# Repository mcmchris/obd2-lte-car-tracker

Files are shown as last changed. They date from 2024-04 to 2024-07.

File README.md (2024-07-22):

# OBD-II LTE Car Tracker
LTE Car Tracker and engine status monitoring connected to the Cloud.

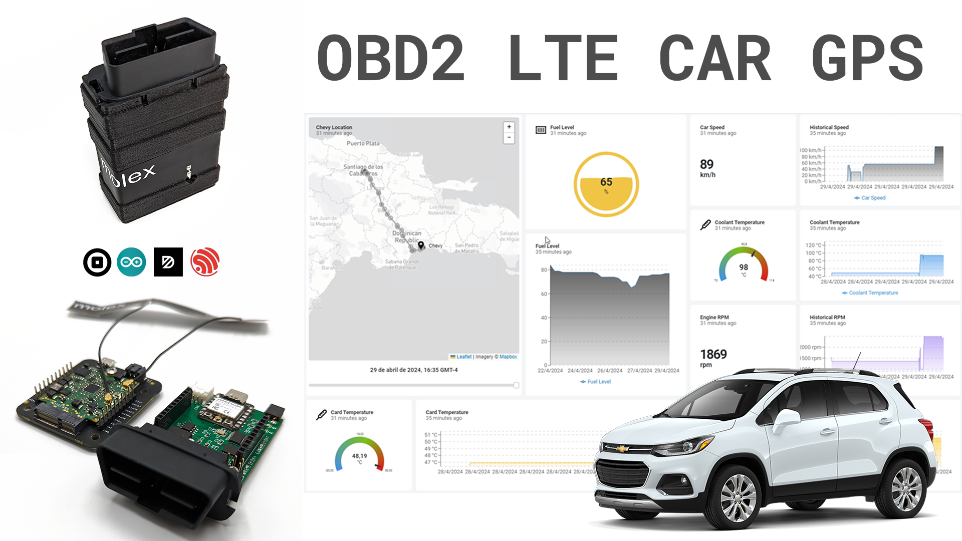
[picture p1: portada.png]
Thumbnail


## Materials

- [XIAO ESP32C3](https://www.seeedstudio.com/Seeed-XIAO-ESP32C3-p-5431.html)
- [Cellular Notecard EMEA](https://shop.blues.com/products/notecard?variant=43940458856689)
- [Notecarrier B](https://shop.blues.com/collections/notecarrier/products/carr-b)
- Custom PCB

## External reference:

- [Serial CAN Module Firmware](https://github.com/Longan-Labs/Serial_CAN_Bus)
- [Longan CAN Module Documentation](https://docs.longan-labs.cc/1030001/)
- [XIAO ESP32C3 Documentation](https://wiki.seeedstudio.com/XIAO_ESP32C3_Getting_Started/)

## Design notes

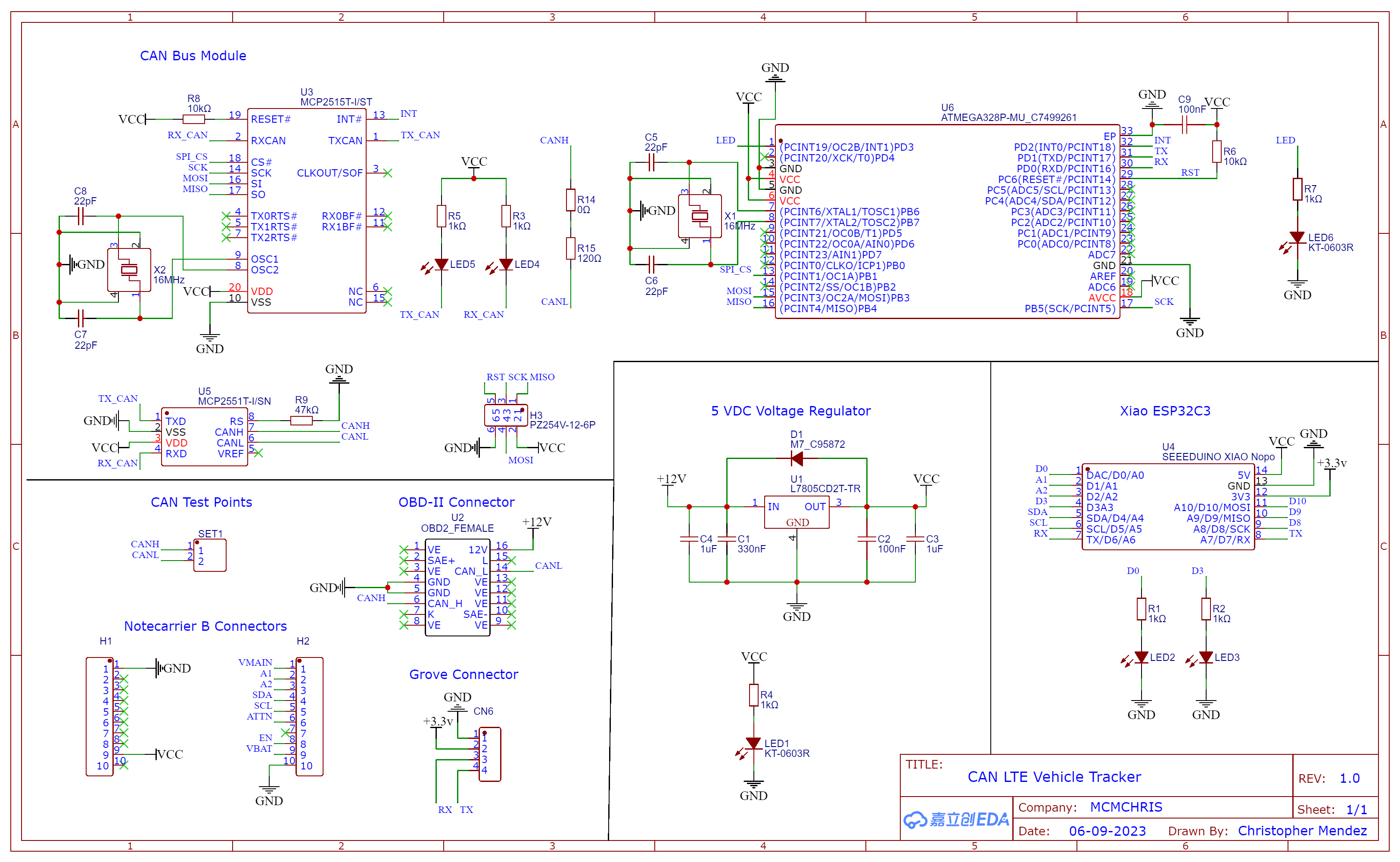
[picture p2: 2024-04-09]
Schematics and PCB files/Schematic_ODB2_car_2024-04-09.png

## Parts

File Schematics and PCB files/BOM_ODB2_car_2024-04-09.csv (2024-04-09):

ID | Name | Designator | Footprint | Quantity | Manufacturer Part | Manufacturer | Supplier | Supplier Part | Price
1 | L7805CD2T-TR | U1 | TO-263-2_L10.0-W9.1-P5.08-LS15.2-TL | 1 |  | ST(意法半导体) | LCSC | C15077 | 0.336
2 | SEEEDUINO XIAO Nopo | U4 | SEEEDUINOXIAO | 1
3 | 330nF | C1 | C0603 | 1 |  | FH(风华) | LCSC | C1615 | 0.01
4 | 100nF | C2,C9 | C0603 | 2 |  | YAGEO(国巨) | LCSC | C14663 | 0.002
5 | 1uF | C3,C4 | C0603 | 2 |  | SAMSUNG(三星) | LCSC | C15849 | 0.005
6 | M7_C95872 | D1 | SMA_L4.3-W2.6-LS5.2-RD | 1 |  | MDD | LCSC | C95872 | 0.007
7 | KT-0603R | LED1,LED6 | LED0603-RD | 2 |  | KENTO | LCSC | C2286 | 0.005
8 | 19-213/Y2C-CQ2R2L/3T(CY) | LED2,LED3,LED4,LED5 | LED0603-RD-YELLOW | 4 |  | EVERLIGHT(亿光) | LCSC | C72038 | 0.019
9 | 1kΩ | R1,R2,R4,R3,R5,R7 | R0603 | 6 | 0603WAF1001T5E | UNI-ROYAL(厚声) | LCSC | C21190 | 0.001
10 | A2008WR-4P | CN6 | CONN-TH_A2008WR-4P | 1 | A2008WR-4P | Changjiang Connectors | LCSC | C273102
11 | 22pF | C5,C6,C7,C8 | C0402 | 4 | 0402CG220J500NT | FH | LCSC | C1555 | 0.001
12 | 10kΩ | R6,R8 | R0402 | 2 | 0402WGF1002TCE | UNI-ROYAL(厚声) | LCSC | C25744 | 0.001
13 | 47kΩ | R9 | R0603 | 1 | 0603WAF4702T5E | UNI-ROYAL(厚声) | LCSC | C25819 | 0.001
14 | 120Ω | R15 | R0603 | 1 | 0603WAF1200T5E | UNI-ROYAL(厚声) | LCSC | C22787 | 0.001
15 | MCP2515T-I/ST | U3 | TSSOP-20_L6.5-W4.4-P0.65-LS6.4-BL | 1 | MCP2515T-I/ST | MICROCHIP(美国微芯) | LCSC | C185941 | 1.252
16 | MCP2551T-I/SN | U5 | SOIC-8_L5.0-W4.0-P1.27-LS6.0-BL | 1 | MCP2551T-I/SN | MICROCHIP(美国微芯) | LCSC | C49558 | 1.009
17 | ATMEGA328P-MU_C7499261 | U6 | HVQFN-32_L5.0-W5.0-P0.50-TL-EP3.1 | 1 | ATMEGA328P-MU | MICROCHIP(美国微芯) | LCSC | C7499261 | 2.526
18 | 16MHz | X1,X2 | OSC-SMD_4P-L3.2-W2.5-BL | 2 | X322516MLB4SI | YXC(扬兴晶振) | LCSC | C13738 | 0.068
19 | PZ254V-12-6P | H3 | HDR-TH_6P-P2.54-V-M-R2-C3-S2.54 | 1 | PZ254V-12-6P | XFCN(兴飞) | LCSC | C492420 | 0.033
20 | OBD2_FEMALE | U2 | OBD2_FEMALE | 1

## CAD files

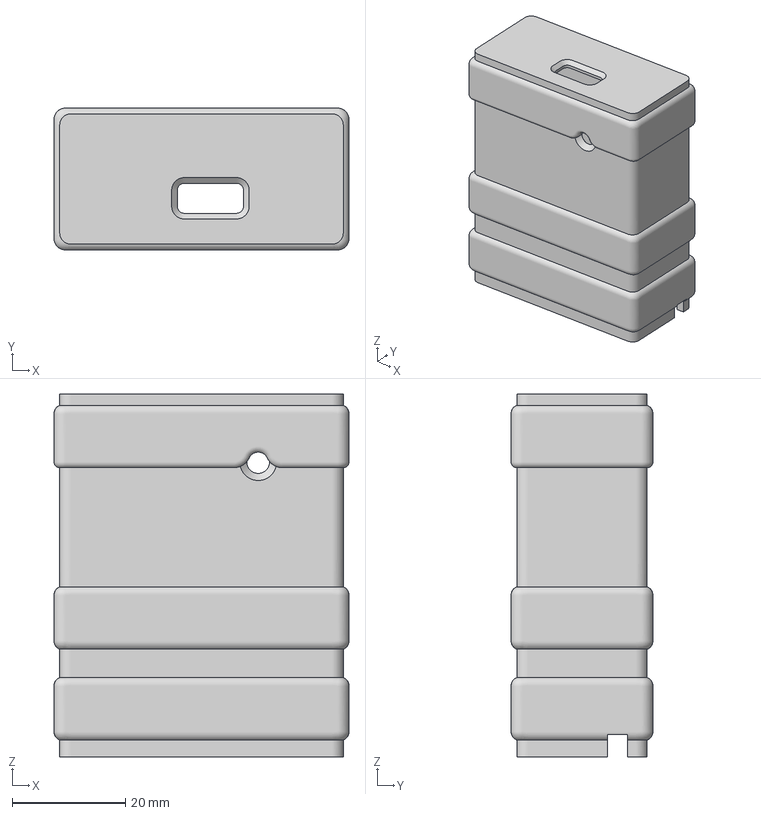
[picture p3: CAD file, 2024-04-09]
3D Files/Case.3mf
52.0 x 25.0 x 64.0 mm

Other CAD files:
3D Files/Case.stl

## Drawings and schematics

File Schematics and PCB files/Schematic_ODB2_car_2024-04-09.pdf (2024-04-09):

## CAN Bus Module

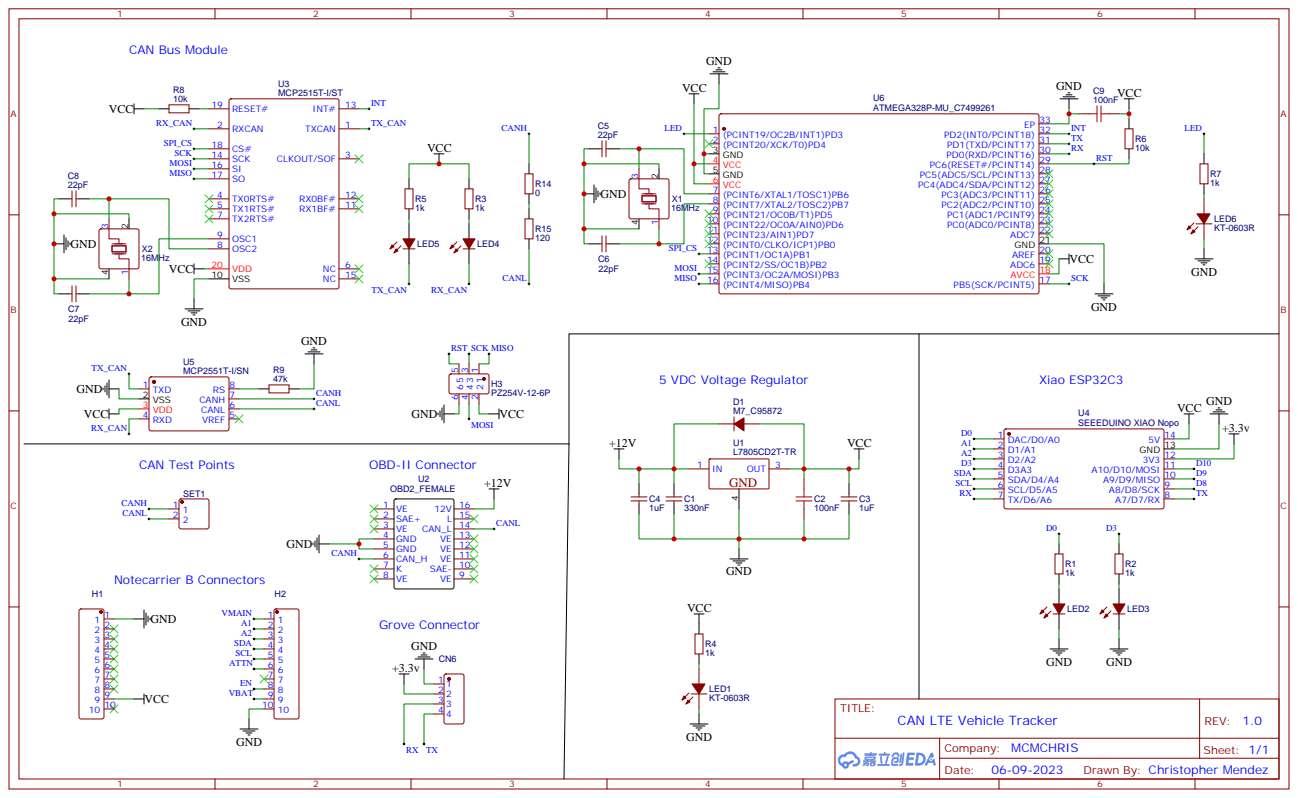
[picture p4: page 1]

SAE- 10 VE 11 VE 12 VE 13 CAN_L 14 L

Drawn By: Christopher Mendez

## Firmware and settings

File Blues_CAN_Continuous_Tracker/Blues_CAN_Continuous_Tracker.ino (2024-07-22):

/*
   MCM - OBD2 Car Tracker

   @Author: Christopher Mendez | MCMCHRIS
   @Date: 04/09/2024 (mm/dd/yy)
   @Brief:
   This firmware runs on a XIAO ESP32C3 microcontroller, it communicates with the vehicle using a CAN-bus transceiver 
   and sends the read data to the Cloud using a Notecard LTE. 

*/

#include <Notecard.h>
#include <Wire.h>
#include <Serial_CAN_Module_ESP.h>

#define serialDebug Serial

#define PRODUCT_UID "***************************"

#define productUID PRODUCT_UID

Notecard notecard;

long previousMillis = 0;
long interval = 60000 * 1;  // 1 minute

Serial_CAN can;

#define STANDARD_CAN_11BIT 1  // That depends on your car. some 1 some 0.

#define PID_ENGIN_PRM 0x0C
#define PID_VEHICLE_SPEED 0x0D
#define PID_COOLANT_TEMP 0x05
#define PID_INTAKE_TEMP 0x0f
#define PID_FUEL_TANK 0x2F  // (100/255)*A
//#define PID_ODOMETER 0xA6

#define LED_A D3
#define LED_B D0


#if STANDARD_CAN_11BIT
#define CAN_ID_PID 0x7DF
#else
#define CAN_ID_PID 0x18db33f1
#endif

int nSpeed = 0;  // speed, 0-200
int nRpm = 0;    // engin speed, 0-999
int nCTemp = 0;  // cooltant temp: 0-999
int nITemp = 0;  //intake temp: 0-999
int nFTank = 0;  // fuel tank level 0-100
float nOdo = 0;

double timeEpoch = 0;
double where_lat = 0;
double where_lon = 0;
double where_when = 0;
double temperature = 0;

bool latch = 0;

/**
 * @brief This function handles the car data send
 */
void sendPid(unsigned char __pid) {
  unsigned char tmp[8] = { 0x02, 0x01, __pid, 0, 0, 0, 0, 0 };
  //Serial.print("SEND PID: 0x");
  //Serial.println(__pid, HEX);

#if STANDARD_CAN_11BIT
  can.send(CAN_ID_PID, 0, 0, 8, tmp);  // SEND TO ID:0X55
#else
  can.send(CAN_ID_PID, 1, 0, 8, tmp);  // SEND TO ID:0X55
#endif
}

/**
 * @brief This function handles the car data requests
 */
unsigned char getPidFromCar(unsigned char __pid, unsigned char *dta) {
  sendPid(__pid);

  unsigned long timer_s = millis();

  while (1) {
    if (millis() - timer_s > 500) {
      return 0;
    }

    unsigned char len = 0;
    unsigned long id = 0;
    if (can.recv(&id, dta))  // check if get data
    {
      if (dta[1] == 0x41 && dta[2] == __pid) {
        return 1;
      }
    }
  }

  return 0;
}

void resetNotecard();
void configureHub();
void configureGPS();
void readFromSensors();

void setup() {
  pinMode(LED_A, OUTPUT);
  pinMode(LED_B, OUTPUT);

  serialDebug.begin(115200);

  for (int i = 0; i < 50; i++) {
    digitalWrite(LED_A, !digitalRead(LED_A));
    delay(100);
  }

  can.begin(TX, RX, 9600);  // ESP32C3 -> TX = D6, RX = D7

  bool set = 0;

  while (set != 1) {
    set = can.baudRate(0);
    delay(200);
    digitalWrite(LED_A, !digitalRead(LED_A));
  }

  notecard.setDebugOutputStream(serialDebug);
  notecard.begin();
  
  //resetNotecard();  // you will need to restore your Notecard if its configured with another unwanted project

  configureHub();
  delay(100);
  configureGPS();
  delay(100);

  for (int i = 0; i < 25; i++) {
    digitalWrite(LED_A, !digitalRead(LED_A));
    delay(200);
  }
  digitalWrite(LED_A, LOW);

  
  readFromSensors();
}

void loop() {

  readFromSensors();  // update the car data

  if (nRpm != 0 && latch == 0) {
    carMeasureReq();
    digitalWrite(LED_A, HIGH);
    if (J *req = notecard.newRequest("hub.sync")) {
      notecard.sendRequestWithRetry(req, 5);  // 5 seconds
    }
    latch = 1;
  } else if (nRpm == 0 && latch == 1) {
    carMeasureReq();
    digitalWrite(LED_A, LOW);
    if (J *req = notecard.newRequest("hub.sync")) {
      notecard.sendRequestWithRetry(req, 5);  // 5 seconds
    }
    latch = 0;
  }
  digitalWrite(LED_B, !digitalRead(LED_B)); // constant blink to verify activity
  delay(1000);
  unsigned long currentMillis = millis();

  // Retrieve car data and create the request to send it to the cloud every interval.
  if ((currentMillis - previousMillis > interval)) {
    previousMillis = currentMillis;
    if (nRpm != 0) {
      digitalWrite(LED_B, HIGH);
      carMeasureReq();
      digitalWrite(LED_B, LOW);
    }
  }
}

/**
 * @brief This function request to the car the different engine variables
 */
void readFromSensors() {

  unsigned char dta[8];

  if (getPidFromCar(PID_VEHICLE_SPEED, dta)) {
    nSpeed = dta[3];
  }
  delay(100);
  if (getPidFromCar(PID_ENGIN_PRM, dta)) {
    nRpm = (256.0 * (float)dta[3] + (float)dta[4]) / 4.0;
  }
  delay(100);
  if (getPidFromCar(PID_COOLANT_TEMP, dta)) {
    nCTemp = dta[3];
    nCTemp = nCTemp - 40;
  }
  delay(100);
  if (getPidFromCar(PID_INTAKE_TEMP, dta)) {
    nITemp = dta[3];
    nITemp = nITemp - 40;
  }
  delay(100);
  if (getPidFromCar(PID_FUEL_TANK, dta)) {
    nFTank = dta[3];
    nFTank = nFTank * (100.0 / 255.0);
  }
  delay(100);
  /*if (getPidFromCar(PID_ODOMETER, dta)) {
    nOdo = dta[3] * pow(2, 24) + dta[4] * pow(2, 16) + dta[5] * pow(2, 8) + dta[6];
    nOdo = nOdo * 0.1;
  }*/

  //Serial.println(nRpm);
  //Serial.println(nSpeed);
  //Serial.println(nCTemp);
  //Serial.println(nITemp);
  //Serial.println(nFTank);
}

/**
 * @brief This function can be used to restore the Notecard
 */
void resetNotecard() {
  J *req = notecard.newRequest("card.restore");
  JAddBoolToObject(req, "delete", true);
  notecard.sendRequest(req);
}

/**
 * @brief This function configures the Notecard's product UID, the mode and communication intervals.
 */
void configureHub() {
  J *req = notecard.newRequest("hub.set");
  JAddStringToObject(req, "product", productUID);
  JAddStringToObject(req, "mode", "periodic");  // the periodic mode set the Notecard to wait the outbound interval to send data.
  //JAddNumberToObject(req, "align", true);
  JAddNumberToObject(req, "outbound", 5);   // every 5 minutes the Notecard will send every data in the queue.
  JAddNumberToObject(req, "inbound", 720);  // every 12 hours the Notecard will check for any incoming update.
  notecard.sendRequestWithRetry(req, 5);  // 5 seconds
}

/**
 * @brief This function configures the Notecard's GPS.
 */
void configureGPS() {
  J *req = notecard.newRequest("card.location.mode");
  JAddStringToObject(req, "mode", "continuous");  // maintain gps on
  //JAddNumberToObject(req, "seconds", 10);
  notecard.sendRequestWithRetry(req, 5);  // 5 seconds
}

/**
 * @brief This function get the car data, location and environment variables read by the Notecard.
 */
void carMeasureReq() {

  J *rsp = notecard.requestAndResponse(notecard.newRequest("card.temp"));
  if (rsp != NULL) {
    temperature = JGetNumber(rsp, "value");
    notecard.deleteResponse(rsp);
  }


  rsp = notecard.requestAndResponse(notecard.newRequest("card.location"));
  if (rsp != NULL) {
    where_lat = JGetNumber(rsp, "lat");
    where_lon = JGetNumber(rsp, "lon");
    where_when = JGetNumber(rsp, "time");
    notecard.deleteResponse(rsp);
  }


  rsp = notecard.requestAndResponse(notecard.newRequest("card.time"));
  if (rsp != NULL) {
    timeEpoch = JGetNumber(rsp, "time");
    notecard.deleteResponse(rsp);
  }
  readFromSensors();

  J *req = notecard.newRequest("note.add");
  if (req != NULL) {
    JAddStringToObject(req, "file", "sensors.qo");
    J *body = JCreateObject();
    if (body != NULL) {
      JAddNumberToObject(body, "where_lat", where_lat);
      JAddNumberToObject(body, "where_lon", where_lon);
      JAddNumberToObject(body, "where_when", where_when);
      JAddNumberToObject(body, "speed", nSpeed);
      JAddNumberToObject(body, "rpm", nRpm);
      JAddNumberToObject(body, "coolant_temp", nCTemp);
      JAddNumberToObject(body, "intake_temp", nITemp);
      JAddNumberToObject(body, "fuel_level", nFTank);
      JAddNumberToObject(body, "temperature", temperature);
      JAddNumberToObject(body, "time", timeEpoch);
      //JAddNumberToObject(body, "odometer", nOdo);
      JAddItemToObject(req, "body", body);
      
    }
    notecard.sendRequest(req);
  }
}

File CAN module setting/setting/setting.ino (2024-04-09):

// MASK&FILE EXAMPLE OF SERIAL CAN MODULE
// SUPPORT: joney.sui@longan-labs.cc
#include <Serial_CAN_Module_ESP.h>

Serial_CAN can;

#define STANDARD_CAN_11BIT      1       // That depands on your car. some 1 some 0. 

#if STANDARD_CAN_11BIT
unsigned long mask[4] = 
{
    0, 0x7FC,                // ext, maks 0
    0, 0x7FC,                // ext, mask 1
};

unsigned long filt[12] = 
{
    0, 0x7E8,                // ext, filt 0
    0, 0x7E8,                // ext, filt 1
    0, 0x7E8,                // ext, filt 2
    0, 0x7E8,                // ext, filt 3
    0, 0x7E8,                // ext, filt 4
    0, 0x7E8,                // ext, filt 5
};

#else
unsigned long mask[4] =
{
    1, 0x1fffffff,               // ext, maks 0
    1, 0x1fffffff,
};
 
unsigned long filt[12] =
{
    1, 0x18DAF110,                // ext, filt
    1, 0x18DAF110,                // ext, filt 1
    1, 0x18DAF110,                // ext, filt 2
    1, 0x18DAF110,                // ext, filt 3
    1, 0x18DAF110,                // ext, filt 4
    1, 0x18DAF110,                // ext, filt 5
};
#endif

void set_mask_filt()
{
    /*
     * set mask, set both the mask to 0x3ff
     */
MASK:
    if(can.setMask(mask))
    {
        Serial.println("set mask ok");
    }
    else
    {
        Serial.println("set mask fail, try again.");
        goto MASK;
    }
FILT:
    /*
     * set filter, we can receive id from 0x04 ~ 0x09
     */
    if(can.setFilt(filt))
    {
        Serial.println("set filt ok");
    }
    else 
    {
        Serial.println("set filt fail, try again");
        goto FILT;
    }
    
}

void setup()
{
    Serial.begin(9600);
    while(!Serial.available());
    can.begin(TX, RX, 9600);      // tx, rx

    set_mask_filt();

}

void loop()
{

}

// END FILE

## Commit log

2024-04-09 Added optional UART pin selection
2024-04-09 3D files, PCB and SCH
    [BOM_ODB2_car_2024-04-09.csv, Case.3mf, Case.stl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]
2024-04-09 setting UART fix
2024-08-27 PCB gerber updated
    Notecard RST pin was routed to Atmega RST pin, this has been fixed.
